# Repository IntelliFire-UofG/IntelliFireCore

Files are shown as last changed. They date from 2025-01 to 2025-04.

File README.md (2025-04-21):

# _**Welcome to IntelliFire UofG Core Repository**_

# 🚒 Autonomous Fire Truck Control System 🔥

### **Real-Time Fire Detection & Response System for Raspberry Pi**

  
  
  
  

## 📌 **Project Description**

The **Autonomous Fire Truck Control System** is an **embedded real-time application** designed for **fire detection and autonomous movement**. Running on a **Raspberry Pi** with **Linux**, this system utilizes an **event-driven architecture** to detect flames via **LM393 flame sensors** (connected through an **ADS1015/ADS1115 ADC**) and control **four motors** via an **L298N motor driver**.
> [!IMPORTANT]
> *Please refer to [Introduction Documentation](https://github.com/IntelliFire-UofG/IntelliFireCore/blob/main/Documentation/Intro.md) if any doubts about functionalities.*
> 
> *Please refer to [STL Files](https://github.com/IntelliFire-UofG/IntelliFireCore/tree/main/STL%20Files) if you wish to 3D print the chassis.*
>
> *Please refer to [Testing README.md](https://github.com/IntelliFire-UofG/IntelliFireCore/blob/testingBranch/tests/README.md) if you wish to review our QA process and some unitTesting tools done with code (Not automated).*
>
> *Please refer to our [Wiki Page](https://github.com/IntelliFire-UofG/IntelliFireCore/wiki) to recap all the retrospectives from our ART (Agile Release Train)*
>
> *Please refer to our [Project Page](https://github.com/orgs/IntelliFire-UofG/projects/1/views/1) to recap all the User Stories from our ART (Agile Release Train)*

## 🔥 **Main Features:**

✅ **Event-driven architecture** (using threads, callbacks, and interrupts).  
✅ **Motor control** for movement based on flame detection.  
✅ **Real-time sensor data processing** using an ADC.  
✅ **Graphical display** for real-time flame visualization.  
✅ **Interrupt-based button control** for manual intervention.  
✅ **Unit testing** for maintainability.  

---

## 🚀 **How It Works**

1️⃣ **System Initialization** → Motors, sensors, buttons, and display are initialized.  
2️⃣ **Register Callbacks** → Sensor readings & button presses trigger motor actions.  
3️⃣ **Start Event Loop** → The system continuously monitors inputs & executes in real time.  
4️⃣ **Fire Detection** → The truck stops moving and logs fire locations.  
5️⃣ **User Interaction** → Buttons allow manual movement control when necessary.  

---

## 🛠 **Tech Stack**

- **Programming Language**: C++  
- **Platform**: Raspberry Pi (Linux)  
- **Architecture**: Object-Oriented Programming (OOP)  
- **Event Handling**: Threads, Callbacks, Interrupts  
- **Visualization**: Qt5  
- **Testing**: Unit testing framework  

---

```bash
📂 IntelliFireCore
 ├── 📂 include                # Header files (Interface definitions)
 │   ├── ads1115rpi.h          # ADS1115 class definition
 │   ├── basicMotion.h         # Motor control class definition
 │   ├── eventLoop.h           # Event loop handling
 │   ├── fireDetector.h        # Event handler for detecting fire
 │   ├── IRSensor.h            # IR sensor class definition
 │   ├── LN298MotorControl.h   # Motor control class definition
 │   ├── pumpControl.h         # Fire extinguishing pump control
 │   ├── UltraSonicSensor.h    # Ultrasonic sensor class definition
 │
 ├── 📂 src                    # Implementation files
 │   ├── 📂 IntelliFireUI      # Graphical UI visualization for sensor data
 │   ├── ads1115manager.cpp    # ADS1115 manager implementation
 │   ├── ads1115rpi.cpp        # ADS1115 implementation
 │   ├── basicMotion.cpp       # Basic motion control implementation
 │   ├── eventLoop.cpp         # Event loop implementation
 │   ├── fireDetector.cpp      # Fire detector implementation
 │   ├── IRSensor.cpp          # IR sensor implementation
 │   ├── keyLogger.cpp         # Key logger implementation
 │   ├── libcam2opencv.cpp     # Camera to OpenCV implementation
 │   ├── LN298MotorControl.cpp # Motor control implementation
 │   ├── main.cpp              # Main entry point, event-driven execution
 │   ├── mainwindow.cpp        # Main window implementation
 │   ├── pumpControl.cpp       # Pump activation logic
 │   ├── sensorContainer.cpp   # Sensor container implementation
 │   ├── UltraSonicSensor.cpp  # Ultrasonic sensor implementation
 │
 ├── CMakeLists.txt            # CMake build configuration
 ├── CODE_REVISION_GUIDELINES.md  # Internal development guidelines
 ├── IntelliFireLogo.png       # Project logo
 ├── LICENSE                   # Apache v2.0 License
 ├── README.md                 # Project documentation
```

---

## 🚦 **Installation & Setup**

### 1️⃣ Prerequisites

Raspberry Pi with Linux
C++ compiler (CMake)
lgpiod (for GPIO control)
ADS1015/ADS1115 ADC module
L298N Motor Driver

### 2️⃣ Build & Run

```bash
ssh -X -C your_rpi_username@your_rpi_hostname

sudo apt update
sudo apt install -y build-essential cmake git pkg-config
sudo apt install -y qtbase5-dev qttools5-dev qttools5-dev-tools
sudo apt install -y libgpiod-dev
sudo apt install -y libcurl4-openssl-dev
sudo apt install -y libqwt-qt5-dev

# Clone the repository
git clone [https://github.com/IntelliFire-UofG/IntelliFireCore.git]

# Navigate to project directory
cd IntelliFireCore

# Create a build folder
mkdir build && cd build

# Compile the project with CMake and Make
cmake ..
make

# Run the executable
./IntelliFireUI (on Raspberry Pi via SSH)

./mediamtx_http_scanner (on local machine)
```

## 📸 **Demo & Screenshots**

(Add images or GIFs showing the system in action!)

---

## 📟 **RPi GPIOs Table**

> [!IMPORTANT]
> Make sure of connecting the following properly, if not ask the team through our different channels.

| IntelliFire Feature | # GPIO |
|:--- |:---:|
| Left Motor PWM | 12 |
| Left Motor FWD | 17 |
| Left Motor BWD | 27 |
| Right Motor PWM | 13 |
| Right Motor FWD | 23 |
| Right Motor BWD | 22 |
| ADS1115 Data R. | 5 |
| ADS1115 I2C SDA | 2 |
| ADS1115 I2C SCL | 3 |
| L393M Flame 1 | 9 |
| L393M Flame 2 | 10 |
| Pump | 11 |
| Ultrasonic Echo | 24 |
| Ultrasonic Trig | 25 |
| IR Presence | 16 |

---

## 🤝 **Contributing**

Contributions are welcome! Please open an issue or submit a pull request.

## 📜 **License**

This project is licensed under the Apache License 2.0.
You can freely use, modify, and distribute it, but you must provide attribution.
See the [LICENSE](https://github.com/IntelliFire-UofG/IntelliFireCore/blob/main/LICENSE) file for details.

## 📞 **Contact & Social Media**

📧 Email: intellifire2025@outlook.com
💼 Instagram: @intellifire25
🌎 Github: [https://github.com/IntelliFire-UofG/]

## 🏷️ **Tags**

C++ Raspberry Pi Event-Driven Programming Real-Time Systems Flame Sensor Motor Control Embedded Systems

# 🔥🚒 Built with passion & innovation! 🚒🔥

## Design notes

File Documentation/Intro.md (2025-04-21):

# IntelliFire: Flame-Responsive Car Control System

## 1. Overview
**IntelliFire** is a Raspberry Pi 5-based, threaded and event-driven robotic platform programmed in C++. It can be controlled via keyboard input and detects fires using a flame sensor array. The system includes live video streaming, real-time UI over SSH, and automatic flame suppression. It integrates multiple sensors to detect both frontal and rear obstacles and logs all events, movements, and sensor data to a remote console.

Additionally, two ARTs (Agile Release Train) were implemented along the project. The main project components can be defined in the following document [Agile Rituals](https://github.com/IntelliFire-UofG/IntelliFireCore/blob/main/Documentation/ARTRituals.md)

---

## 2. Core Components

### 2.1 Flame Detection System
A 4-element LM393 IR flame sensor array is interfaced through an ADS1015 analog-to-digital converter. Each sensor provides continuous analog signals indicating flame presence and proximity. These are read at fixed intervals, translated into directional inference, and displayed on the UI.

### 2.2 Video Streaming
A Raspberry Pi Camera module streams live video through an **MTX Media Server**. The stream is accessible locally on the same network, allowing visual confirmation of navigation and flame conditions.

### 2.3 Obstacle Detection
- **Ultrasonic Sensor (HC-SR04)** mounted at the front calculates distances based on pulse reflection time. The system alerts or stops the car when obstacles are too close.
- **IR Presence Sensor** at the rear detects objects within a short range, useful for safe reversing. Both sensors are reflected in the UI when active.

### 2.4 Motion Control
The car uses four DC motors driven by an L298N H-Bridge. Each motor pair (left/right) is controlled by:
- PWM signals for velocity (fixed profiles).
- Forward and backward direction pins.

### 2.5 Flame Suppression
A directional water pump is triggered via GPIO when a flame is detected based on the sensor array. The decision is based on analog thresholds and relative intensity across the four sensors. The action and flame location are logged in the UI.

---

## 3. User Interface (UI)
Accessible via SSH, the UI displays:
- Real-time analog values from the flame sensors.
- Distance from ultrasonic sensor.
- Rear object detection status from the IR sensor.
- Pressed/released keys with current movement status.
- Whether the flame suppression pump is activated.

The UI remains responsive and continuously updates via a dedicated thread loop.

---

## 4. Software Architecture

### 4.1 Multithreading & Event Handling
The system operates through separate threads, each responsible for:
- Sensor polling (ADS1015, ultrasonic, IR).
- Keyboard input detection.
- Motor actuation control.
- UI rendering.
- Video streaming (handled externally by MTX Media).

All modules use mutex-protected shared queues and callback-based event triggers to ensure thread safety and low latency.

### 4.2 Error Handling
Each subsystem implements robust error-checking:
- I2C/ADS1015 read failures are captured with retry and fallback mechanisms.
- Ultrasonic timeouts and misreads are filtered.
- Motor driver logic includes fail-safe motor stops if input is invalid or lost.

### 4.3 Codebase Separation
The code is split into:
- **Hardware Layer**: Interfaces with all sensors, actuators, and communication buses.
- **Application/UI Layer**: Manages the user interface, sensor readings, and command execution logic.

This separation ensures maintainability and scalability of the system.

---

## 5. Pin Allocation Table

| IntelliFire Feature | GPIO Pin |
|---|---|
| Left Motor PWM | 12 |
| Left Motor FWD | 17 |
| Left Motor BWD | 27 |
| Right Motor PWM | 13 |
| Right Motor FWD | 23 |
| Right Motor BWD | 22 |
| ADS1015 Data Ready  | 5 |
| I2C SDA (ADS1015) | 2 |
| I2C SCL (ADS1015) | 3 |
| Flame Sensor 1 | 9 |
| Flame Sensor 2 | 10 |
| Water Pump | 11 |
| Ultrasonic Echo | 24 |
| Ultrasonic Trig | 25 |
| IR Rear Presence | 16 |

---

## 6. Work Principle Summary
1. Upon startup, all sensor modules initialize and start continuous polling threads.
2. UI begins listening to keyboard commands over SSH.
3. Key events are mapped to directional motor commands using PWM with fixed speed settings.
4. Flame sensors constantly feed analog data into the UI and logic controller.
5. If flame presence surpasses a threshold, the water pump is activated.
6. Obstacle detection from front and rear updates the UI and may halt or reverse the car.
7. Every sensor state, action taken, and input received is logged in real-time on the remote UI.

---

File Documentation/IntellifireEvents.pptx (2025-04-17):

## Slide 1

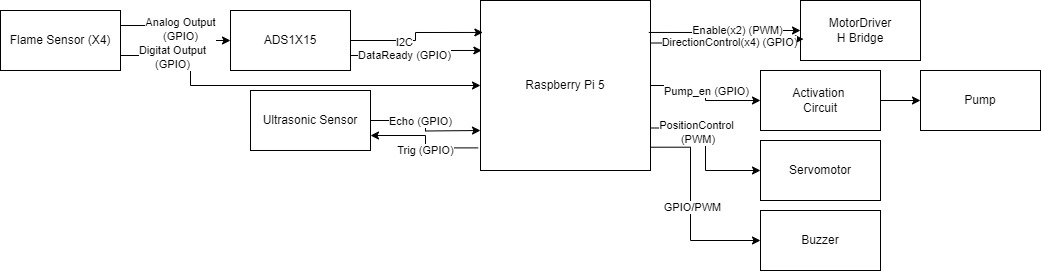
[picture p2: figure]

Events
- FlameDetection: Rising edge on GPIO connected to Flame Sensor (x4), when a flame is detected on any of the sensors.
- DataReady ADC: Rising edge on GPIO connected to Data Ready pin on ADC integrated circuit once a new analogue measurement is ready.
Timers
- Ultrasonic sensor : Trigger the sensor measurement periodically in pseudo blocking timer

## Flame distance idea

Starting from the assumption of having a very narrow angle of detection in the sensors; We can set two sensors at a known distance a from each other and with a known angle θ from the horizontal axis.
If we position the robot in an orientation in which both sensors measure the flame with the same intensity, we may assume we are b distance apart from the flame source.

a

b

θ

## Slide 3

However, the IR sensor has a detection angle of 60°. That means that we will have a range of distance detection.
We won’t be able to know the exact distance, but at least we will know that the flame is within certain range.

Considerations:
I think we will need to have two sets of flame sensors. One with at least 3 sensors to detect the direction of the flame source. And a second one with this configuration.
This way, the robot can scan the surroundings until it finds the flame and once the robot is positioned in the right orientation it can start to approach the flame until the source is within the range of the second set of sensors.
We can place the sensors in a way in which the range of detection match the range of operation of the water pump.

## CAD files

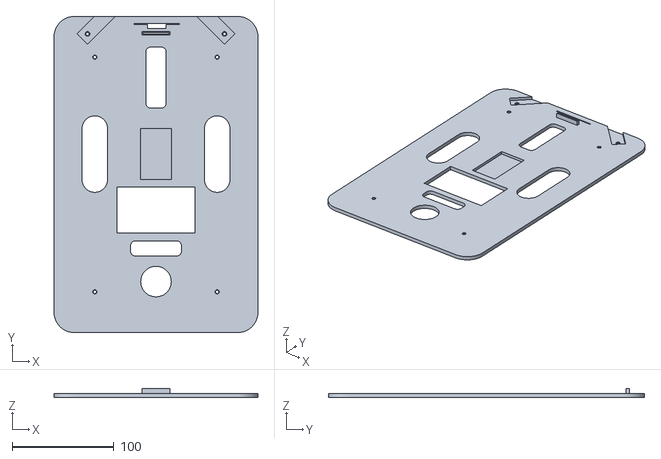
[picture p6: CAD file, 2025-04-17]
STL Files/upper.stl
200.0 x 310.0 x 9.00

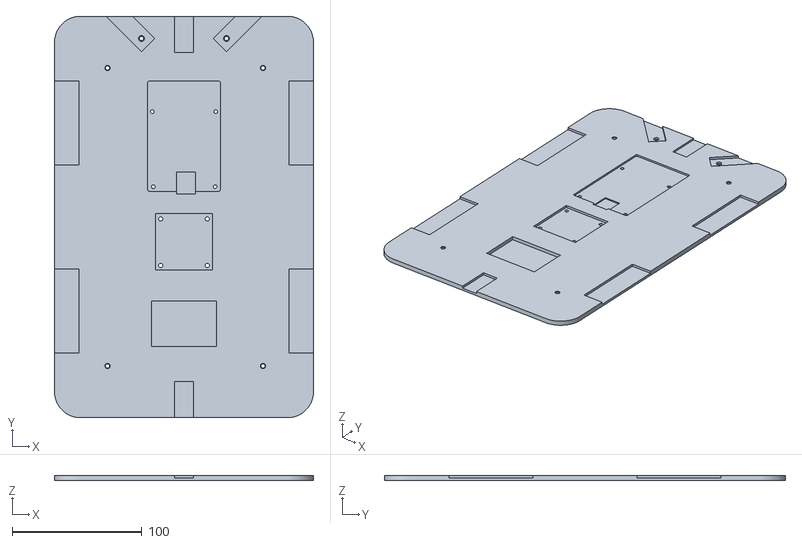
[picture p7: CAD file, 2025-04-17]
STL Files/lower.stl
200.0 x 310.0 x 4.00

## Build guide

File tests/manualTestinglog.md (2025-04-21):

# IntelliFire Manual Testing Report

**Project:** IntelliFire  
**Platform:** Raspberry Pi 5  
**Test Date:** 2025-04-18  
**Tester:** Misael Rivera, Shahmurad Orujov, Mohammed Al-Obaidly
**Environment:** SSH-connected terminal UI, MTX media stream, live sensors/motors.

---

## Flame Sensor Array + Water Pump

### Test Case: Detect Flame in Path
- **Setup:** L393M sensors placed 10 cm from a lighter flame.
- **Expectation:** One or more sensors report (analog), pump triggers.
- **Result:**
  - Sensor Readings: `[120, 130, 740, 125]`
  - Direction Detected: Index 2
  - Water Pump: Triggered
  - UI Message: `Flame detected at direction 2 — Pump Activated`

**Passed**

---

### Test Case: No Flame Present
- **Setup:** All sensors exposed to ambient lighting only.
- **Expectation:** No sensor surpasses threshold, pump remains off.
- **Result:**
  - Sensor Readings: `[0, 0, 2, 0]`
  - UI Message: `No flame detected`
  - Water Pump: Not Triggered

**Passed**

---

## Ultrasonic and IR Presence Sensors

### Test Case: Obstacle Ahead at 15 cm
- **Setup:** Place object in front of ultrasonic sensor at ~15 cm.
- **Expectation:** UI logs the distance, car halts.
- **Result:**
  - Distance Read: `14.8 cm`
  - UI Message: `14.8 cm`
  - Car State:  Stopped

**Passed**

---

### Test Case: Obstacle Behind Detected
- **Setup:** Hand placed 5 cm behind IR presence sensor.
- **Expectation:** UI logs presence, optional rear alert.
- **Result:**
  - UI Message: `Obstacle detected`
  - Buzzer/PWM: N/A

**Passed**

---

## Keyboard Control (Keylogger)

### Test Case: Key Presses and Releases
- **Setup:** Use SSH terminal to control car via keyboard.
- **Keys Tested:** `W`, `A`, `S`, `D`, `Space`
- **Expectation:** UI displays keypress, motors respond.
- **Result:**
  - Press `W`: `Key Pressed: W — Moving Forward`
  - Press `Space`: `Key Pressed: Space — Stopping`
  - Motor GPIO Activity: Verified via motor movement

**Passed**

---

## Video Stream via MTX Media

### Test Case: Stream Opens on Localhost
- **Setup:** Connect to `RPI URL designated by team`
- **Expectation:** Live stream with <2s latency.
- **Result:**
  - Stream loads: Yes
  - Latency: ~1.3s
  - Video Quality: Acceptable (640x480)

**Passed**

---

## User Interface (SSH)

### Test Case: Display Sensor and System Status
- **Setup:** Open SSH and launch UI script.
- **Expectation:** UI logs all sensor values, states, and events.
- **Result:**
  - Flame Sensors: Analog values shown live
  - Obstacles: Realtime updates on detection
  - Keys & Motors: Input/output confirmed
  - Pump Status: On/Off toggle appears

**Passed**

---

## Threading & Event Handling

### Test Case: Simultaneous Inputs (Flame + Obstacle + Movement)
- **Setup:** While moving forward, trigger flame and place object ahead.
- **Expectation:** Car stops, pump activates, all events logged.
- **Result:**
  - Motors halted on obstacle
  - Pump triggered for flame
  - UI logs all 3: `Flame detected when analog values are increased`, `Obstacle ahead`, `Key Pressed: W`

**Passed**

---

## Reboot & Recovery

### Test Case: Power Cycle Device
- **Expectation:** All threads/services restart without manual intervention.
- **Result:**
  - Services auto-launch: Correct
  - UI starts via ssh: Correct
  - Camera stream rebinds: Correct if scripts are run

**Passed**

---

# Final Summary

| Module | Tests Run | Passed | Issues |
|---|---|---|---|
| Flame Detection | 10 | 10 | 0 |
| Obstacle Sensing | 3 | 3 | 0 |
| Keyboard Control | 3 | 2 | 1 - Solved |
| Video Streaming | 2 | 2 | 0 |
| UI Logging | 5 | 3 | 2 - Solved |
| Thread/Event Mgmt  | 2 | 2 | 0 |
| Reboot Recovery | 2 | 2 | 0 |

**Total:** 9 Tests, All Passed 
**Status:** System Ready for Deployment

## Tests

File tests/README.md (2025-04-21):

# IntelliFire - Test Scenarios

This document outlines the test scenarios for the IntelliFire flame-detection car system. The tests cover functionality, integration, performance, and fail-safe behavior for each major subsystem.

The testing stage was done on the last sprint of our ART (Agile Release Train)

---

## 1. Flame Sensor Array (LM393 via ADS1015)

### Test 1.1: Sensor Read Validity
- **Objective**: Ensure each flame sensor reports analog values in expected range (0–1023).
- **Steps**: 
  - Run the system without flame.
  - Introduce a lighter or flame source at various angles.
- **Expected Result**: 
  - Analog values increase for the sensor closest to the flame.
  - UI displays all 4 sensor values correctly.

### Test 1.2: Flame Direction Estimation
- **Objective**: Detect flame direction based on sensor with highest value.
- **Steps**: 
  - Place flame to the left, center, right.
- **Expected Result**: 
  - The correct directional inference is logged.
  - Water pump is directed accordingly.

### Test 1.3: ADS1015 Failure Handling
- **Objective**: Validate error handling on I2C communication failure.
- **Steps**: 
  - Disconnect ADS1015 briefly while running.
- **Expected Result**: 
  - UI logs I2C failure.
  - No crash occurs, and system attempts reconnection.

---

## 2. Water Pump Trigger

### Test 2.1: Automatic Activation
- **Objective**: Trigger the pump only when flame is detected.
- **Steps**:
  - Approach a flame gradually.
- **Expected Result**:
  - Pump is activated when threshold is passed.
  - Pump deactivates when flame is gone.

### Test 2.2: No False Positives
- **Objective**: Ensure pump doesn’t activate due to ambient IR or noise.
- **Steps**:
  - Shine an IR remote or flashlight in front.
- **Expected Result**:
  - Pump remains inactive.
  - UI does not indicate flame detection.

---

## 3. Ultrasonic Sensor (Obstacle Ahead)

### Test 3.1: Obstacle Detection Accuracy
- **Objective**: Measure and log distance accurately.
- **Steps**:
  - Place a wall/object at known distances (10cm, 20cm, 50cm).
- **Expected Result**:
  - UI reflects correct measurements within ±5cm.

### Test 3.2: No Echo Handling
- **Objective**: Test behavior when no echo is received.
- **Steps**:
  - Point sensor at open space.
- **Expected Result**:
  - Timeout occurs, UI shows "No object".
  - No crash or hang.

---

## 4. IR Presence Sensor (Obstacle Behind)

### Test 4.1: Rear Detection Trigger
- **Objective**: Detect presence of object from the rear.
- **Steps**:
  - Move hand slowly behind the car.
- **Expected Result**:
  - UI indicates obstacle presence.
  - Appropriate alert or movement restriction occurs if active.

---

## 5. Motor & Motion Control

### Test 5.1: Keyboard Movement
- **Objective**: Control the car with key presses.
- **Steps**:
  - Press keys: W (forward), S (backward), A (left), D (right).
- **Expected Result**:
  - Motors respond accordingly.
  - UI logs key press and corresponding direction.

### Test 5.2: Motor Fail-safe
- **Objective**: Stop all motors on error or key release.
- **Steps**:
  - Simulate input drop or release key.
- **Expected Result**:
  - Motors stop immediately.
  - UI shows “idle” or “stopped”.

---

## 6. UI System (SSH Terminal)

### Test 6.1: Real-time Updates
- **Objective**: Ensure all sensor data, key events, and actions are reflected.
- **Steps**:
  - Activate each sensor and press keys.
- **Expected Result**:
  - UI updates all fields in <1s.
  - No lag or freezing.

### Test 6.2: Long-run Stability
- **Objective**: Validate system over extended runtime.
- **Steps**:
  - Run IntelliFire for 1 hour.
- **Expected Result**:
  - No memory leaks or crashes.
  - UI remains responsive.

---

## 7. Camera Streaming (MTX Media)

### Test 7.1: Stream Availability
- **Objective**: Verify live stream availability on local network.
- **Steps**:
  - Start MTX server and camera.
  - Open stream URL on browser.
- **Expected Result**:
  - Live video displays with <1s delay.

### Test 7.2: Performance Under Load
- **Objective**: Validate system with both camera and UI active.
- **Steps**:
  - Move the car while streaming and viewing UI.
- **Expected Result**:
  - No significant delay in UI or video.
  - Motors and sensors remain unaffected.

---

## 8. Integration & Edge Cases

### Test 8.1: Flame + Obstacle + Movement
- **Objective**: Handle flame detection and obstacle presence during motion.
- **Steps**:
  - Approach a flame while an object is behind.
- **Expected Result**:
  - Car moves, detects flame, activates pump.
  - IR sensor prevents reversing.

### Test 8.2: Full System Recovery
- **Objective**: Simulate reboot and check restoration.
- **Steps**:
  - Power cycle the device.
- **Expected Result**:
  - All threads restart.
  - UI, motors, and sensors function normally.

---

## 9. Logging & Debug

### Test 9.1: Error Message Clarity
- **Objective**: Ensure errors are logged clearly.
- **Steps**:
  - Simulate sensor failure or GPIO conflict.
- **Expected Result**:
  - Log includes sensor name, error type, and suggested fix.

---

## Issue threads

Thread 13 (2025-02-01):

Power Supply for LN298

Misael-R, 2025-02-01:
## Not enough Power Supply for Motor Control

LN298 Driver needs adequate Power Supply [12 V // 10 A].
This blocker is preventing us to test Motor Control Code from **_./SupportCodes_** and **_./test_**
@Abdul1996-7  will continue this investigation.

Bypass options:

> Powerbank
> 9V Battery Box

Consider test from #9

Misael-R, 2025-02-05:
@Abdul1996-7  any updates on this?

orujovshah, 2025-02-05:
> 9V Battery box will be tested for each Motor. It will feed just directly to the driver regards @orujovshah heads up.

As it is said ins the Osoyoo's official site "The module can utilize the built-in stabilivolt tube 78M05 to obtain 5v from the power supply. But to protect the chip of the 78M05 from damage, when the drive voltage is greater than 12v, an external 5v logic supply should be used."

Misael-R, 2025-02-07:
**_Resolution:_** Okay, team has agreed to use a Battery Box below 12 V to avoid damage to 78M05. Its gonna feed just the LN298 Controller. Auxiliary power supply will be added to the rest of the system.

> Last Update: 07 February 2025
> Given by: Shahmurad Orujov

Closed 2025-02-07.

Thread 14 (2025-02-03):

DIstance Measure for Fire Location

Misael-R, 2025-02-03:
At this point there is no idea of how to map the position of the flame. Just get the intensity or use ultrasonic sensor for detecting the source.

Needs to have a rodmap to tackle this.

Misael-R, 2025-02-03:
@moal-obaidly  commented on stand up that he has code for Ultrasonic Sensor with Raspberry Pi! 👍

Brendacg616-uofg, 2025-02-03:
@Abdul1996-7 @moal-obaidly @Misael-R
Hi guys, please give this doc a look, and tell me if the idea to detect the flame makes sense to you.
https://github.com/IntelliFire-UofG/IntelliFireCore/blob/DocumentationBranch/Documentation/IntellifireEvents.pptx

Misael-R, 2025-02-05:
@Abdul1996-7
MLX906 its also a good approach, my only worry is the budget and how is it gonna be applied to a event-driven scheme. As @Brendacg616-uofg commented might not be 100% adapted to our scope. Let's discuss it with all the team

orujovshah, 2025-02-05:
> For the for detecting the fire we can use MLX90614 so that will help us to do these things: ✅ use MLX90614, you do NOT need a separate flame sensor or thermal resistor. ✅ MLX90614 detects fire AND estimates distance based on heat intensity. ✅ The robot stops at a safe distance based on real-time fire temperature readings. ✅ Event-driven execution (NO DELAYS) ensures real-time responsiveness.

Did some research, and came to the conclusion that it is quite expensive and might not fit our budget. Also, its band of measurements for the IR radiation is too narrow, might cause a problem. Still not rejecting the idea, would be better to discuss it as a team.

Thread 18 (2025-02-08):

UI Initial Development

Misael-R, 2025-02-08:

Misael-R, 2025-02-08:
## Begin with Code Structure of IntelliFire UI.

**Summary: Needs to contain something about Sensors Reading, Motor control and UI Desgin.**
 ---

#TODO:

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

---

**Story Points** 👍 👍 👍 👍 👍

Closed 2025-02-12.

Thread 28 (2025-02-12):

Patrol Sequence - Motor control

Misael-R, 2025-02-12:
Consider programming a square patrol for a certain area.
Get a sensor value to do an alternate sequence (i.e. Obstacle avoidance or stop motors)

Closed 2025-02-24.

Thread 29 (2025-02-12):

Connect Sensor Values to the UI

Misael-R, 2025-02-12:
Get info from ADS Inputs and display into the different sensor containers

Misael-R, 2025-02-15:
This will consider now distance sensors such as Ultrasonic and IR Presence

Closed 2025-02-26.

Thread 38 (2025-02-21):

Missing Left ,right ,fw and bw functions

Abdul1996-7, 2025-02-21:
@abood-zm I can not see the functions for for the motor in either .h and .cpp files ?

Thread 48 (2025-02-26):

Ultrasonic and IR Sensor Instance on SensorContainer Source

Misael-R, 2025-02-26:
## Wrong code structure on sensorContainer.cpp

The following code considers IRSensor struct from SensorContainer header file but must be incorporated under src/sensorContainer.cpp instead to match with previous workflow.

```c++
#ifndef SENSORCONTAINER_H
#define SENSORCONTAINER_H

#include <QWidget>
#include <QLabel>
#include "UltraSonicSensor.h"
#include "ir_sensor.h"

class SensorContainer : public QWidget, public IRSensor::IRSensorCallbackInterface {
    Q_OBJECT
```

Consider testing all previous features after modifying the instantiation.

> Misael Rivera
> Feb 26th

Misael-R, 2025-03-15:
This issue still up, but no causing bugs

Misael-R, 2025-03-15:
Changing this will improve the code struct

Misael-R, 2025-03-31:
This might be considered for 2nd ART

Misael-R, 2025-03-31:
This might be considered for 2nd ART

Closed 2025-03-31.

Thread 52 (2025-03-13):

Water Pump Control Circuit

Misael-R, 2025-03-13:
Circuit Building for triggering the pump action.
Flag for pumping action or not (Either in UI or Physical LED)

Abdul1996-7, 2025-03-21:
For Power Connections if the Buck converter is not availbe we can use linear voltage regulater to step down the voltage from the power supply (9v to 5v) and it is availbe in the electronic shop.

For Diode Protection only one diod is enough for the protection ,but two also two would be good approch and the diod is availbe in the electronic shop.

Closed 2025-03-22.

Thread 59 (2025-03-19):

Key Releasing Event

Misael-R, 2025-03-19:
## Key Releasing event is not working

While testing, it is not possible to identify when a key is released. Probably due to not mapping the events correctly

> [!IMPORTANT]
> This is a critical feature issue

> 19th March 2025
> Misael Rivera

Misael-R, 2025-03-23:
The feature has been well instantiated and bug solved for keyReleaseEvent fcn under SensorContainer.cpp

Closed 2025-03-23.

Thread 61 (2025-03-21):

Feature Request: Replace GPIO ON/OFF with Real PWM for Motor Speed Control

Abdul1996-7, 2025-03-21:
Description: Currently, the Motor class uses simple GPIO ON/OFF control to enable or disable the motor using the pwm pin (ENA/ENB). This approach works for basic movement but does not support speed control or gradual acceleration.

Goal: Upgrade the motor control logic to use real PWM output on the PWM (ENA/ENB) pin instead of binary HIGH/LOW values, allowing control over motor speed.

Try to use Bernd Porr PWM driver code

https://github.com/berndporr/rpi_pwm

abood-zm, 2025-03-23:
I added the implementation of the PWM to the motor controls in the main branch. Please have a look and let me know.

abood-zm, 2025-03-25:
I added everything. Please check it out.

Abdul1996-7, 2025-04-06:
@abood-zm

I have updated the code in my branch, so now it is working based on the hardware pwm instead of software pwm

these files were included in the  include file rpi_pwm and in the src/rpi_pwm.cpp

try to integrate them in the main file and let me know

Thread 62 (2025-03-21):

Design 5V Power Supply with L7805CV

Abdul1996-7, 2025-03-21:
Design a simple and stable 5V regulated power supply circuit using the L7805CV voltage regulator. This circuit will be used to provide clean 5V DC for waterpump.

**Components**
1- L7805CV  voltage regulater
2- Input voltage: 7V–12V DC like current battery 9V
3-capacitors for stability (10µF on input and output)

**Output**
Stable 5V

Closed 2025-03-24.

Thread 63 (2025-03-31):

Error Handling for Each Sensor Container

Misael-R, 2025-03-31:
Error Handling techniques for

- Ultrasonic Sensor
- IR Presence Sensor
- Flame Sensors
- Camera Displaying
- Pump Activation

Closed 2025-04-09.

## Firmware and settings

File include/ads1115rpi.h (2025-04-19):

#ifndef __ADS1115RPI_H
#define __ADS1115RPI_H

/*
 * ADS1115 class to read data at a given sampling rate
 *
 * Copyright (c) 2007  MontaVista Software, Inc.
 * Copyright (c) 2007  Anton Vorontsov <avorontsov@ru.mvista.com>
 * Copyright (c) 2013-2024  Bernd Porr <mail@berndporr.me.uk>
 *
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
 */
#include <stdint.h>
#include <unistd.h>
#include <stdio.h>
#include <stdlib.h>
#include <assert.h>
#include <linux/i2c-dev.h>
#include <thread>
#include <gpiod.h>
#include <vector>
#include <atomic>
#include <mutex>

// enable debug messages and error messages to stderr
#ifndef NDEBUG
#define DEBUG
#endif

static const char could_not_open_i2c[] = "Could not open I2C.\n";

#ifndef ISR_TIMEOUT
#define ISR_TIMEOUT 1000
#endif

// default address if ADDR is pulled to GND
#define DEFAULT_ADS1115_ADDRESS 0x48

// default GPIO pin for the ALRT/DRY signal
#define DEFAULT_ALERT_RDY_TO_GPIO 5

/**
 * ADS1115 initial settings when starting the device.
 **/
struct ADS1115settings {

    int i2c_bus = 1;
    uint8_t address = DEFAULT_ADS1115_ADDRESS;

    enum SamplingRates {
        FS8HZ = 0,
        FS16HZ = 1,
        FS32HZ = 2,
        FS64HZ = 3,
        FS128HZ = 4,
        FS250HZ = 5,
        FS475HZ = 6,
        FS860HZ = 7
    };

    inline unsigned getSamplingRate() const {
        const unsigned SamplingRateEnum2Value[8] = {8, 16, 32, 64, 128, 250, 475, 860};
        return SamplingRateEnum2Value[samplingRate];
    }

    SamplingRates samplingRate = FS8HZ;

    enum PGA {
        FSR6_144 = 0,
        FSR4_096 = 1,
        FSR2_048 = 2,
        FSR1_024 = 3,
        FSR0_512 = 4,
        FSR0_256 = 5
    };

    PGA pgaGain = FSR2_048;

    enum Input {
        AIN0 = 0,
        AIN1 = 1,
        AIN2 = 2,
        AIN3 = 3
    };

    Input channel = AIN0;
    int drdy_chip = 0;
    int drdy_gpio = DEFAULT_ALERT_RDY_TO_GPIO;
};

/**
 * This class reads data from the ADS1115 in the background (separate
 * thread) and calls a callback function whenever data is available.
 **/
class ADS1115rpi {

public:
    ADS1115rpi() = default;

    ~ADS1115rpi() {
        stop();
    }

    ADS1115rpi(const ADS1115rpi&) = delete;
    ADS1115rpi& operator=(const ADS1115rpi&) = delete;

    ADS1115rpi(ADS1115rpi&&) = delete;
    ADS1115rpi& operator=(ADS1115rpi&&) = delete;

    struct ADSCallbackInterface {
        virtual void hasADS1115Sample(float sample) = 0;
	virtual ~ADSCallbackInterface() = default;
    };

    void registerCallback(ADSCallbackInterface* ci) {
        std::lock_guard<std::mutex> lock(callback_mutex);
        adsCallbackInterfaces.push_back(ci);
    }

    void setChannel(ADS1115settings::Input channel);
    void start(ADS1115settings settings = ADS1115settings());
    ADS1115settings getADS1115settings() const {
        return ads1115settings;
    }
    void stop();

private:
    ADS1115settings ads1115settings;

    void dataReady();
    void worker();
    void i2c_writeWord(uint8_t reg, unsigned data);
    unsigned i2c_readWord(uint8_t reg);
    int i2c_readConversion();

    const uint8_t reg_config = 1;
    const uint8_t reg_lo_thres = 2;
    const uint8_t reg_hi_thres = 3;

    float fullScaleVoltage() {
	switch (ads1115settings.pgaGain) {
    case ADS1115settings::FSR6_144:
        return 6.144f;
    case ADS1115settings::FSR4_096:
        return 4.096f;
	case ADS1115settings::FSR2_048:
	    return 2.048f;
	case ADS1115settings::FSR1_024:
	    return 1.024f;
	case ADS1115settings::FSR0_512:
	    return 0.512f;
	case ADS1115settings::FSR0_256:
	    return 0.256f;
	}
	assert(1 == 0);
	return 0;
    }

    struct gpiod_chip* chipDRDY = nullptr;
    struct gpiod_line* pinDRDY = nullptr;

    std::thread thr;
    std::atomic<bool> running{false};

    int fd_i2c = -1;

    std::vector<ADSCallbackInterface*> adsCallbackInterfaces;
    std::mutex callback_mutex;
};

#endif // __ADS1115RPI_H

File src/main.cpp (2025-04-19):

/**
 * @file main.cpp
 * @brief Autonomous Fire Truck Control System - Entry Point
 *
 * This embedded real-time system runs on a Raspberry Pi and controls an autonomous 
 * fire truck equipped with four motors (L298N driver) and a flame detection system 
 * (LM393 sensors via ADS1015/ADS1115 ADC). The system responds to fire events and 
 * user inputs in real time, using an event-driven architecture.
 *
 * @author Misael Rivera
 * @date 2025-02-01
 */

#include "../include/LN298MotorControlV3.h"
#include "../include/basicMotionV2.h"
// #include "../include/ADCReader.h"
#include <iostream>
#include <thread>
#include <atomic>
#include <memory>

int main() {
    std::cout << "🔥 Autonomous Fire Truck System Initializing... 🔥" << std::endl;
    
    // Initialize ADC Reader for flame sensors
    //ADCReader adcReader(0x48);  // I2C address for ADS1015/ADS1115 
    
    // Register ADC callback to react to fire detection
    //adcReader.registerFlameCallback([](int channel, int value) {
        //std::cout << "🔥 Flame detected on sensor " << channel << " with value: " << value << std::endl;
        // Note: This callback can't directly control motors created in basicMotion()
    //});
    
    // Start the basic motion system with keyboard control
    std::cout << "Starting keyboard control system..." << std::endl;
    
    // Call the basicMotion function defined in basicMotionV3.cpp
    int result = basicMotion();
    
    std::cout << "Basic motion system exited with code: " << result << std::endl;
    std::cout << "Shutting down..." << std::endl;
    
    return result;
}

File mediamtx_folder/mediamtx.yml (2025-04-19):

###############################################
# Global settings

# Settings in this section are applied anywhere.

###############################################
# Global settings -> General

# Verbosity of the program; available values are "error", "warn", "info", "debug".
logLevel: info
# Destinations of log messages; available values are "stdout", "file" and "syslog".
logDestinations: [stdout]
# If "file" is in logDestinations, this is the file which will receive the logs.
logFile: mediamtx.log

# Timeout of read operations.
readTimeout: 10s
# Timeout of write operations.
writeTimeout: 10s
# Size of the queue of outgoing packets.
# A higher value allows to increase throughput, a lower value allows to save RAM.
writeQueueSize: 512
# Maximum size of outgoing UDP packets.
# This can be decreased to avoid fragmentation on networks with a low UDP MTU.
udpMaxPayloadSize: 1472

# Command to run when a client connects to the server.
# This is terminated with SIGINT when a client disconnects from the server.
# The following environment variables are available:
# * MTX_CONN_TYPE: connection type
# * MTX_CONN_ID: connection ID
# * RTSP_PORT: RTSP server port
runOnConnect:
# Restart the command if it exits.
runOnConnectRestart: no
# Command to run when a client disconnects from the server.
# Environment variables are the same of runOnConnect.
runOnDisconnect:

###############################################
# Global settings -> Authentication

# Authentication method. Available values are:
# * internal: users are stored in the configuration file
# * http: an external HTTP URL is contacted to perform authentication
# * jwt: an external identity server provides authentication through JWTs
authMethod: internal

# Internal authentication.
# list of users.
authInternalUsers:
  # Default unprivileged user.
  # Username. 'any' means any user, including anonymous ones.
- user: any
  # Password. Not used in case of 'any' user.
  pass:
  # IPs or networks allowed to use this user. An empty list means any IP.
  ips: []
  # List of permissions.
  permissions:
    # Available actions are: publish, read, playback, api, metrics, pprof.
  - action: publish
    # Paths can be set to further restrict access to a specific path.
    # An empty path means any path.
    # Regular expressions can be used by using a tilde as prefix.
    path:
  - action: read
    path:
  - action: playback
    path:

  # Default administrator.
  # This allows to use API, metrics and PPROF without authentication,
  # if the IP is localhost.
- user: any
  pass:
  ips: ['127.0.0.1', '::1']
  permissions:
  - action: api
  - action: metrics
  - action: pprof

# HTTP-based authentication.
# URL called to perform authentication. Every time a user wants
# to authenticate, the server calls this URL with the POST method
# and a body containing:
# {
#   "user": "user",
#   "password": "password",
#   "ip": "ip",
#   "action": "publish|read|playback|api|metrics|pprof",
#   "path": "path",
#   "protocol": "rtsp|rtmp|hls|webrtc|srt",
#   "id": "id",
#   "query": "query"
# }
# If the response code is 20x, authentication is accepted, otherwise
# it is discarded.
authHTTPAddress:
# Actions to exclude from HTTP-based authentication.
# Format is the same as the one of user permissions.
authHTTPExclude:
- action: api
- action: metrics
- action: pprof

# JWT-based authentication.
# Users have to login through an external identity server and obtain a JWT.
# This JWT must contain the claim "mediamtx_permissions" with permissions,
# for instance:
# {
#  ...
#  "mediamtx_permissions": [
#     {
#       "action": "publish",
#       "path": "somepath"
#     }
#   ]
# }
# Users are expected to pass the JWT in the Authorization header or as a query parameter.
# This is the JWKS URL that will be used to pull (once) the public key that allows
# to validate JWTs.
authJWTJWKS:
# name of the claim that contains permissions.
authJWTClaimKey: mediamtx_permissions

###############################################
# Global settings -> Control API

# Enable controlling the server through the Control API.
api: no
# Address of the Control API listener.
apiAddress: :9997
# Enable TLS/HTTPS on the Control API server.
apiEncryption: no
# Path to the server key. This is needed only when encryption is yes.
# This can be generated with:
# openssl genrsa -out server.key 2048
# openssl req -new -x509 -sha256 -key server.key -out server.crt -days 3650
apiServerKey: server.key
# Path to the server certificate.
apiServerCert: server.crt
# Value of the Access-Control-Allow-Origin header provided in every HTTP response.
apiAllowOrigin: '*'
# List of IPs or CIDRs of proxies placed before the HTTP server.
# If the server receives a request from one of these entries, IP in logs
# will be taken from the X-Forwarded-For header.
apiTrustedProxies: []

###############################################
# Global settings -> Metrics
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

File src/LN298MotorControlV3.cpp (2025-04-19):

#include "LN298MotorControlV3.h"
#include "rpi_pwm.h"
#include <iostream>
#include <cstdlib>
#include <atomic>
#include <thread>
#include <termios.h>
#include <unistd.h>
#include <fcntl.h>
#include <chrono>
#include <memory>
#include <stdexcept>
#include <system_error>
#include "keyLogger.h"

// Motor Constructor: Initializes the motor with given parameters.
Motor::Motor(int pwm_channel, int in1_pin, int in2_pin, int dutyCycle, const std::string& name) 
    : chip(nullptr), in1_pin(in1_pin), in2_pin(in2_pin), pwm_channel(pwm_channel), 
      dutyCycle(dutyCycle), motorName(name) {
    
    // Get the logger instance
    logger = Logger::getInstance();
    logger->log("Initializing motor: " + motorName);
    
    try {
        // Initialize the PWM signal on the given PWM channel with 100 Hz frequency and the specified duty cycle
        if (pwm.start(pwm_channel, 100, dutyCycle) < 0) {
            throw std::runtime_error("Failed to initialize PWM on channel " + std::to_string(pwm_channel));
        }
        
        // Initialize GPIO pins and set them to low initially
        std::system(("gpioset gpiochip0 " + std::to_string(in1_pin) + "=0").c_str());
        std::system(("gpioset gpiochip0 " + std::to_string(in2_pin) + "=0").c_str());
        
        logger->log("Motor " + motorName + " initialized successfully");
    }
    catch (const std::exception& e) {
        logger->log("ERROR initializing motor " + motorName + ": " + e.what());
        throw; // Re-throw the exception for higher level handling
    }
}

// Function to move the motor forward
void Motor::moveForward() {
    pwm.setDutyCycle(75);  // Set PWM duty cycle to 75% for forward movement (High speed)

    // Set motor direction using GPIO pins: IN1=1, IN2=0
    std::system(("gpioset gpiochip0 " + std::to_string(in1_pin) + "=1").c_str());
    std::system(("gpioset gpiochip0 " + std::to_string(in2_pin) + "=0").c_str());
    
    // Log the action
    logger->logMotorAction(motorName, "forward");
}

// Function to move the motor backward
void Motor::moveBackward() {
    pwm.setDutyCycle(75);  // Set PWM duty cycle to 75% for backward movement (High speed)

    // Set motor direction using GPIO pins: IN1=0, IN2=1
    std::system(("gpioset gpiochip0 " + std::to_string(in1_pin) + "=0").c_str());
    std::system(("gpioset gpiochip0 " + std::to_string(in2_pin) + "=1").c_str());
    
    // Log the action
    logger->logMotorAction(motorName, "backward");
}

// Function to stop the motor
void Motor::stop() {
    pwm.setDutyCycle(0);  // Set PWM duty cycle to 0% to stop the motor (No power)
    
    // Set motor control pins to 0 (both low) to stop the motor
    std::system(("gpioset gpiochip0 " + std::to_string(in1_pin) + "=0").c_str());
    std::system(("gpioset gpiochip0 " + std::to_string(in2_pin) + "=0").c_str());
    
    // Log the action
    logger->logMotorAction(motorName, "stop");
}

// Function to adjust motor speed by changing the duty cycle
void Motor::setSpeed(int speed) {
    if (speed < 0 || speed > 100) {
        logger->log("WARNING: Invalid speed value: " + std::to_string(speed) + ". Speed must be between 0-100");
        return;
    }
    
    dutyCycle = speed;  // Update duty cycle
    pwm.setDutyCycle(dutyCycle);  // Apply the new duty cycle
    
    // Log the action
    logger->logMotorAction(motorName, "speed set to " + std::to_string(speed));
}

// Motor Destructor: Stops the motor and cleans up resources
Motor::~Motor() {
    logger->log("Shutting down motor: " + motorName);
    stop();  // Make sure the motor is stopped
    pwm.stop();  // Stop the PWM signal
    
    // Clean up GPIO chip if it was allocated
    if (chip != nullptr) {
        gpiod_chip_close(chip);
        chip = nullptr;
    }
}

// Setup terminal for non-canonical mode (character-by-character input)
int setupTerminal(KeyboardState& state) {
    struct termios newt;
    
    // Get the current terminal attributes and save them
    if (tcgetattr(STDIN_FILENO, &state.originalTermios) < 0) {
        std::cerr << "Error: Unable to get terminal attributes" << std::endl;
        return -1;
    }
    
    // Copy the original settings and modify them
    newt = state.originalTermios;
    
    // Disable canonical mode and echo, enable non-blocking reads
    newt.c_lflag &= ~(ICANON | ECHO);
    newt.c_cc[VMIN] = 0;  // Non-blocking read
    newt.c_cc[VTIME] = 0; // No timeout
    
    // Apply the new settings
    if (tcsetattr(STDIN_FILENO, TCSANOW, &newt) < 0) {
        std::cerr << "Error: Unable to set terminal attributes" << std::endl;
        return -1;
    }
    
    // Set stdin to non-blocking mode
    int flags = fcntl(STDIN_FILENO, F_GETFL, 0);
    fcntl(STDIN_FILENO, F_SETFL, flags | O_NONBLOCK);
    
    return 0;
}

// Restore original terminal settings
void restoreTerminal(KeyboardState& state) {
    // Set stdin back to blocking mode
    int flags = fcntl(STDIN_FILENO, F_GETFL, 0);
    fcntl(STDIN_FILENO, F_SETFL, flags & ~O_NONBLOCK);
    
    // Restore original terminal settings
    tcsetattr(STDIN_FILENO, TCSANOW, &state.originalTermios);
}
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

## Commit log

2025-01-25 Added Support code for LM393 Sensor Reading
2025-01-27 Added Support Code for Motor Drive (Bckward and Fwd direction)
2025-01-27 Added README for Motor Support Code
2025-02-01 Added code for motor to test it. This is version 0
2025-02-01 Revert "Added meaningless code"
    [mainwindow.cpp]
2025-02-01 Added i2c struct for 4 sensor array
2025-02-01 Defined main event threads and callback implementation from h struct
2025-02-06 Added a test for the flame sensor with Raspberry Pi
2025-02-07 Modify code to control only one motor, just speed and direction
2025-02-07 Add DifferentialRobot class to SupportCodes just in case is useful in the future
2025-02-08 Added png for sensors
2025-02-09 Fixed issues in the header files and added basic logic for the motors. Code needs to be reviewed and tested
    [main.cpp]
2025-02-10 Revert "Fixed issues in the header files and added basic logic for the motors…"
    [main.cpp]
2025-02-10 made a few changes to allow for the image to load properly. Also made images scale to the correct size
    [sensorContainer.cpp]
2025-02-10 Added the correct library for the GPIO, defined the pins required for the motors, included basicMotion header file, Initialized controllers for both motors (left and right) created basicMotion object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
    [main.cpp]
2025-02-10 Defined the MotorController Function. Added a new condition for when the speed is 0 in the setMotorSpeed function. Defined a basic logic for the setPWMDuty function (Needs Proper review). Wrote the c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
2025-02-10 ADS1015 driver based on ADS1115 driver
2025-02-12 WIP CMakeLists.txt for ADC MultiChannel test
2025-02-12 Create FlameSensorReader for 4 channel sensor reading
2025-02-12 Created ShahBranch and adder IR Sensor folder
2025-02-13 Created ShahBrach and added all the files for IR Sensor.
2025-02-13 Removed 'IR Sensor' folder from ShahBranch
2025-02-15 Modified the codes for IR Sensor
2025-02-15 Added the code for Ultra Sonic Sensor and update CMakeLists.txt.
2025-02-15 Added test for IR Sensor.
2025-02-15 Updated README file to include both sensors.
2025-02-15 Implemented ADS1115 Manager, Mapped the containers separately with pointer, initialize ADS1115 which is going to get & update sensors values
2025-02-15 Update each label from each container regards the pass value. Corrected some typos
    [sensorContainer.cpp]
2025-02-15 Added docsting and slots param values
2025-02-15 Added header for ads, will initialize the sensor Idx and values with the start and stop methods
2025-02-15 This implements the start with settings @64hz and 4chip RPI5, stop and get sample for sensor
2025-02-15 Added containers for distance sensors
2025-02-15 Conditional for distance sensors titles, title and label declared before
2025-02-15 Added build with 2 additional sensors
2025-02-17 added fattah's logic to the motor controller.
2025-02-18 header file for ultrasonicdistance.cpp
2025-02-18 test ultrasonic distance code to test the UI
2025-02-18 added the ultrasonicDistance.cpp and linked libgpiod library
2025-02-18 Added the implementation to update the UI with ultrasonic distance measurements. Also cleaned up the code and made some changes to how the titles and values are set. (using settext ->). Finally linke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
2025-02-19 added shahs ultrasonic sensor with a signal added
2025-02-19 Added files to test UI with Sensors.
2025-02-19 Updated CMakeLists to use both UI and UltraSonicSensor.
2025-02-20 Added the README for Sensors.
2025-02-22 Tested Motor Code with basic motions
2025-02-24 Initialized key logger for UI, on each callback for key, printing public function
2025-02-24 Corrected path to Ultrasonic sensor
2025-02-24 Corrected paths and applied keylogger functionalities
    [main.cpp, mainwindow.cpp]
2025-02-25 added camera integration with UI. Displayed to the right of the keylogger. Still need to test on RPI
2025-02-25 Implementation of camera taken from Bernd Porr
2025-02-25 header for the camera
2025-02-25 Changed header to include the camera integration and callbacks to libcam
2025-02-25 changed from using slots and signals to Q_SLOTS and Q_SIGNALS. They're the same thing but i'm unable to use the former due to the camera implementation
2025-02-25 changed the CMakeLists to account for the camera implementation.
2025-02-26 Unblocked sensor containers for IR and Ultrasonic
2025-02-26 Added switch map to sensorContainer type, skipped if tree
    [sensorContainer.cpp]
2025-02-26 Consider separate fcns for updating Ultrasonic and IR sensor
2025-02-26 Mapped new QT_SIGNALS and pointers to separate UltraSonic and IR
2025-02-28 Motor control with Keyboard buutons
2025-03-03 Fix ultrasonic sensor container
    [sensorContainer.cpp]
2025-03-05 ADC connected to UI but incorrect containers
2025-03-05 Flame sensors container display fixed
    [sensorContainer.cpp]
2025-03-05 Revert "Flame sensors container display fixed"
    This reverts commit 0014d7e05185353416a3ea2427b034b8df9b577a.
    [sensorContainer.cpp]
2025-03-05 Revert "ADC connected to UI but incorrect containers"
    This reverts commit 2315d9b072c22fe9af0c6dbb050a6cbaedaca605.
    [sensorContainer.cpp]
2025-03-05 Fix ADC scale calculation
    [ads1115rpi.cpp, ads1115rpi.h]
2025-03-05 Fix the number of decimals in the Fire Sensor containers
    [sensorContainer.cpp]
2025-03-12 Moved SensorContainer to src
2025-03-12 Staged changes for deletion
2025-03-12 Modified sensorcontainer to src
2025-03-12 Pump Activation - Sometimes fails, bug fix needed
    [fireDetector.cpp, fireDetector.h, main.cpp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]
2025-03-15 Added the pump indicator for emmitting signal
2025-03-15 Mapped release event for mainwindow flow
2025-03-15 Pump indicator in the UI connected to pump status
2025-03-15 Clean up the code and missing CMakeLists.txt
    [mainwindow.cpp, pumpControl.cpp, pumpControl.h]
2025-03-18 Modified the main and created a separate thread for the basicMotion
2025-03-18 fixed the LN298 file
    [LN298MotorControlV3.cpp]
2025-03-21 Update basicMotionV3.cpp
    GPIO pins for rightMotor swapped for correct motion
    [basicMotionV3.cpp]
2025-03-22 Restablished GPIO for pump, defined by team
2025-03-22 Set Ultrasonic/IR GPIOs, defined by team
2025-03-22 Removed the camera from QT UI.
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2025-03-22 Removed README for sensors, not needed in main branch.
2025-03-23 Upgrade motor control header with PWM capabilities for speed controladded cmake file
2025-03-23 Update basicMotion to use PWM channels instead of GPIO for motor control
2025-03-23 Implement PWM-based speed control using Bernd Porr's PWM driver
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2025-03-31 Added STL for 3D Printing
    [IntelliFireChassisv12.stl]
2025-04-06 Update motor control files and add rpi_pwm support
2025-04-07 Added error handling to each container and ccritical warnings
    [sensorContainer.cpp]
2025-04-07 No need this altogether file
    [IntelliFireChassisv12.stl]
2025-04-07 Added both loweBody and Topbody files for printing
    [LowerBody.stl, TopBody.stl]
2025-04-08 Changes based on DevelopmentBranch. Reverted motor and keylogger related changes for Aboot to work on.
    [IntelliFireChassisv12.stl]
2025-04-08 Fixed small issues occuring during the building process.
    [ads1115rpi.h, fireDetector.h, main.cpp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]
2025-04-09 Change gpios to avoid clashes
    [ads1115rpi.h, pumpControl.h, sensorContainer.cpp]
2025-04-09 Small fixes to make code safer
    [ads1115rpi.h, mainwindow.cpp]
2025-04-09 Change fire detector pin definitions to correct file
    [fireDetector.h]
2025-04-09 Emit IR sensor value instead of change it directly
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2025-04-11 Deleted unecessary stls
    [lower.stl, upper.stl]
2025-04-11 Deleted unecessary stls with upper and lower
    [LowerBody.stl, TopBody.stl]
2025-04-11 merged error handling with shahs code
    [UltraSonicSensor.cpp]
2025-04-11 merged IR error handling with shahs code
    [IRSensor.cpp]
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2025-04-15 Fixed Motor Control for Directions. FWD/BWD/LEFT/RIGHT now works.
    [LN298MotorControlV3.cpp]

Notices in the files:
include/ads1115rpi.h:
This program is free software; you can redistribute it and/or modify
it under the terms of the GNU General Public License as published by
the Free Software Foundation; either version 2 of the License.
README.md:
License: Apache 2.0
